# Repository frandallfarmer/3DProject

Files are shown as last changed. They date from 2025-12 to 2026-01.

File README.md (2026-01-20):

# D&D Terrain Pillar Connector

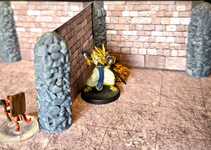
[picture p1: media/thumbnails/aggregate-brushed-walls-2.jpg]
Dry brushed aggregate pillars with dungeon walls
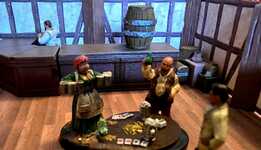
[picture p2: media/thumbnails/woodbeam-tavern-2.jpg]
Woodbeam pillars and tavern walls
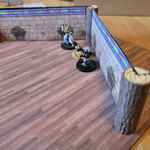
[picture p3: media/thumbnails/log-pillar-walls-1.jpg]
Two color log beams with temple walls
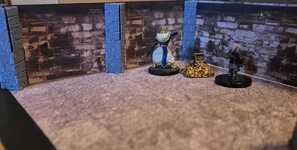
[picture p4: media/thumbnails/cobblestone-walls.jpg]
Cobblestone pillars with custom dungeon walls


3D printable pillar connector for tabletop RPG paper terrain [repo](https://github.com/frandallfarmer/3DProject) compatible with Paper Realm's tab-and-slot wall model. https://paperrealms.com

## Description

This pillar connector is designed to work with paper cardstock dungeon walls. The connector features slots on all four sides that accept paper wall tabs, allowing you to build modular dungeon interiors and building layouts. Paper Realms is also contributing templates and cutfiles for their tab-and-slot design model for anyone to customize for personal use!

This project was facilitated by [OldSchoolDM](http://oldschooldm.com), a paper-craft terrain aficionado, and implemented by [frankfarmer](https://github.com/frankfarmer). The driving desire was to support the minimum storage requirements for gaming terrain for dungeons and buildings. Inspired by the tab-and-slot design of Paper Realms, we wanted to add some heft - sturdiness and weight to the connectors. 3D Printing seemed like the perfect thing to hybrid with these compact but very detailed wall designs.

**[→ View 3D Models in Interactive Viewer](viewer.html)**

## The Walls

Paper Realms has contributed templates for you to customize your own paper walls to use with the 3D printed connectors (pillars) for this project.
These pillars are compatible with existing 2" Paper Realm's walls - that's been on of our requirements for this project.

See the walls [README](https://github.com/frandallfarmer/3DProject/tree/master/wall-templates) for more.

## The Pillars

### Specifications

- **Height:** 2 inches (50.8mm)
- **Cross-section:** 2/3" × 2/3" square (16.93mm)
- **Slots:** Four slots (one per face), centered, running 1" down from top
- **Construction:** Hollow with 2mm walls to save filament
- **File format:** STL for 3D printing

### Files

- `pillar_connector.scad` - OpenSCAD source file (parametric, editable)
- `pillar_connector.stl` - Ready-to-print STL file

### Printing

Standard PLA settings should work fine. The model is designed for FDM/FFF printers with typical 0.4mm nozzles.

 * Required:
  * "Detect thin walls" or "Wall generator: arachne"
 * Optional:
  * Nominal layer height: <= 0.20 mm
  * "Variable Layer Height"

Use "Detect thin walls" ensures your slicer doesn't skip the "paper-thin" segments that fit the wall slots.  Keeping these thin slots allows compatibilty with preexisting paper wall designs.

### Customization

The OpenSCAD file is parametric. Edit the parameters at the top of `pillar_connector.scad` to adjust:
- Pillar height
- Face width
- Slot dimensions
- Wall thickness

Regenerate the STL with:
```bash
openscad -o pillar_connector.stl pillar_connector.scad
```

## STL Viewer

This repository includes a web-based STL viewer for previewing all models. The viewer features:
- Split-screen interface with file list and 3D preview
- Interactive rotation and zoom controls
- Automatic file list generation

### Viewing Currently Available Models

**Online:** Visit https://frandallfarmer.github.io/3DProject/viewer.html to view all models in your browser.

**Locally:**

```bash
python3 -m http.server 8000
```
Then open http://localhost:8000/viewer.html in your browser.

## License

Everything here is under CC BY-SA-4.0, except the ViewSTL js files, which are under MIT - https://sourceforge.net/projects/viewstl/ for the latest.

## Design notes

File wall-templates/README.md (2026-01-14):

This project was inspired by the paper terrain from Paper Realms.

See https://paperrealms.com for links to their various paper terrain models, including several different wall designs (some shown in the photos you can see in the /media directory.

## Instructions

These .png files are templates you can use to create your own custom textured walls: 

1) Open the wall size you want in an image editor and paste your wall texture between the silver posts

2)  Print on heavy cardstock (at least 65lb/175gsm),

3) Cut using 

   a hobby knife or

   the matching file provided in ./cutfiles with a Silhouette cutting machine

4) Fold in half and use a black marker to edge the top/bottom.

5) Glue.

6) Let dry under some weight.

7) Enjoy!

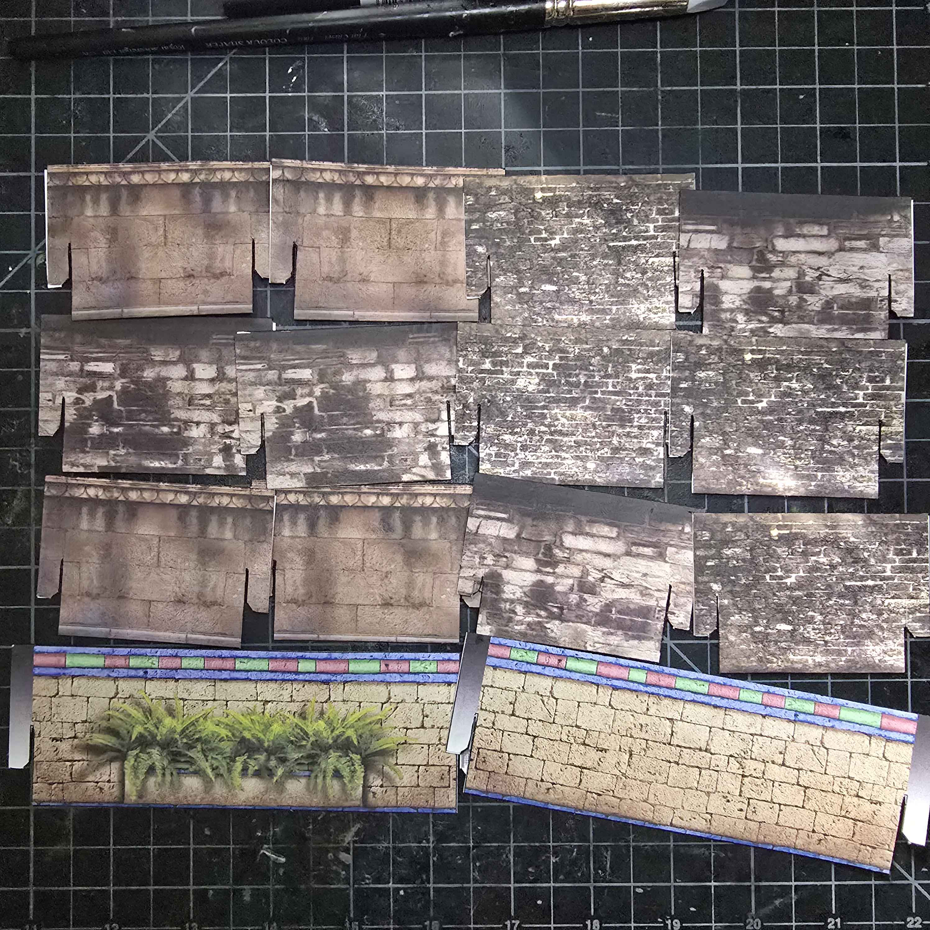
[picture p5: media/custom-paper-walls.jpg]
kitbashed walls


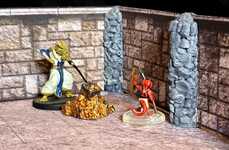
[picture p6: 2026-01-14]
media/thumbnails/aggregate-brushed-walls-3.jpg

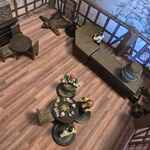
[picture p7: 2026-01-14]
media/thumbnails/woodbeam-tavern-1.jpg

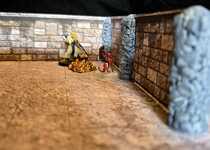
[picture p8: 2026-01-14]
media/thumbnails/aggregate-brushed-walls-1.jpg

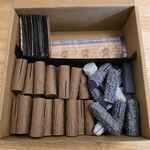
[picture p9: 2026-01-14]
media/thumbnails/box-of-walls-and-posts.jpg

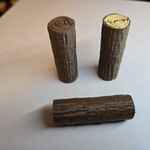
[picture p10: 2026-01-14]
media/thumbnails/1-and-2-color-logs.jpg

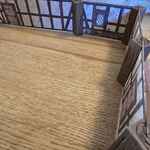
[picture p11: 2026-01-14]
media/thumbnails/woodbeam-tavern-3.jpg

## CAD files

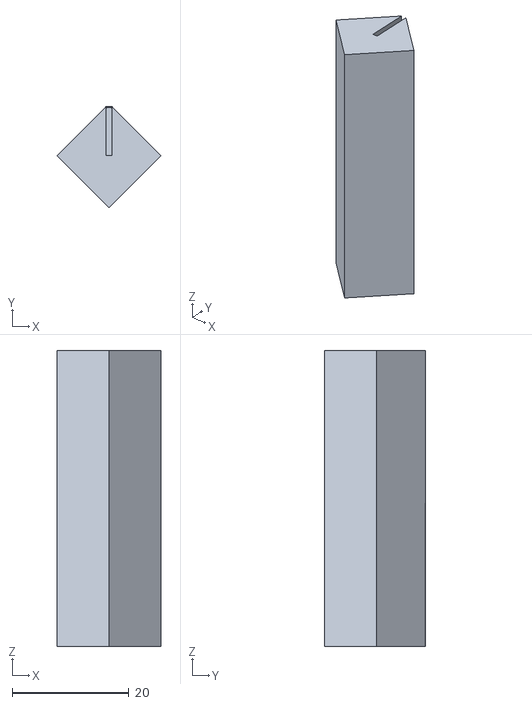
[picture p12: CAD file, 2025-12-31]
built_stls/output_slimrect_end.stl
17.9 x 17.4 x 50.8

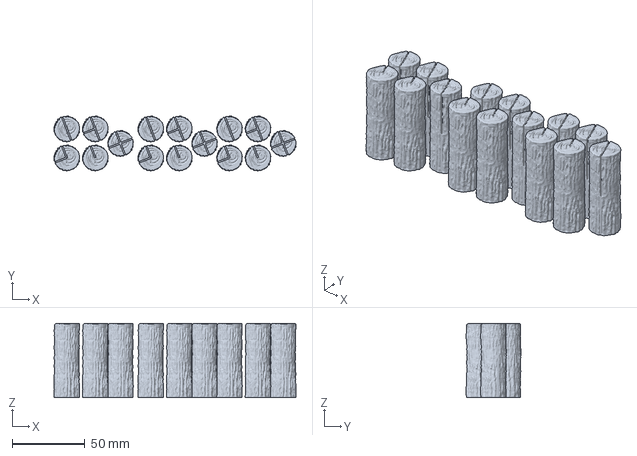
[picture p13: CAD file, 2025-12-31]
log_with_color.3mf
166.0 x 37.8 x 50.8 mm

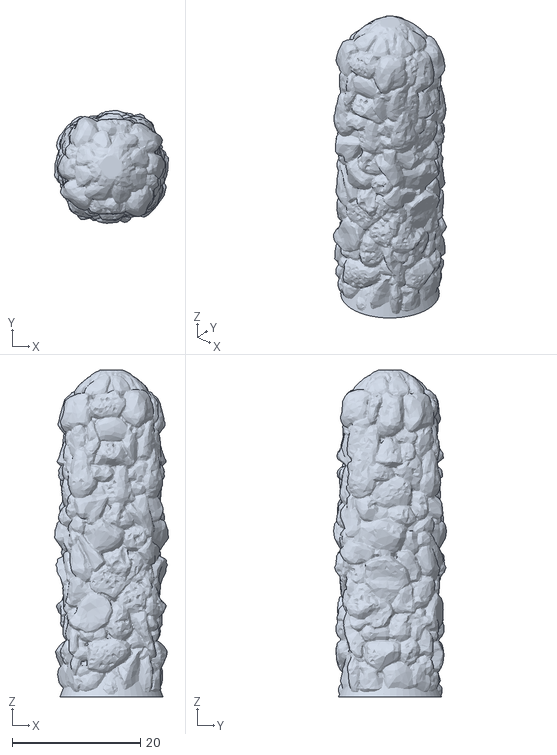
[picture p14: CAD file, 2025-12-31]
src/aggregate.stl
17.8 x 17.6 x 51.0

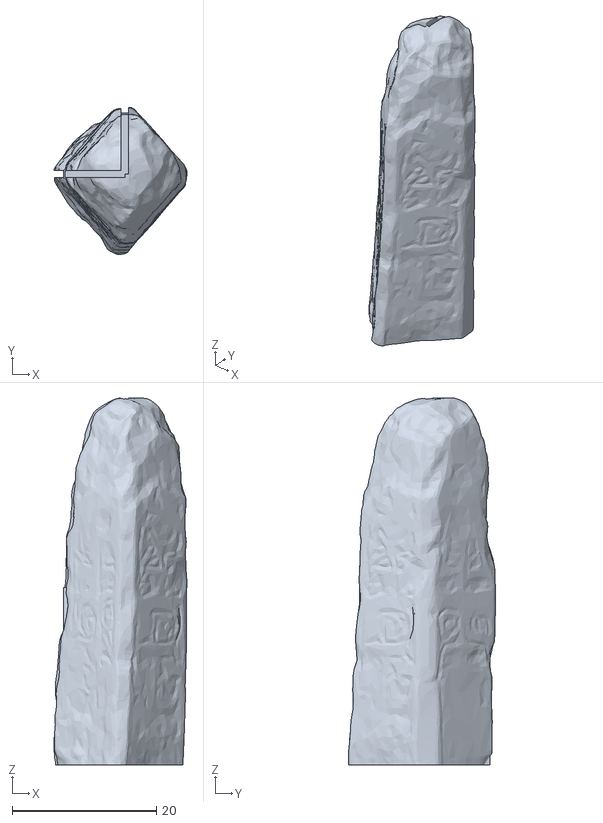
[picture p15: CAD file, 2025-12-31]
built_stls/output_slimhengestone_corner.stl
18.4 x 20.4 x 50.8

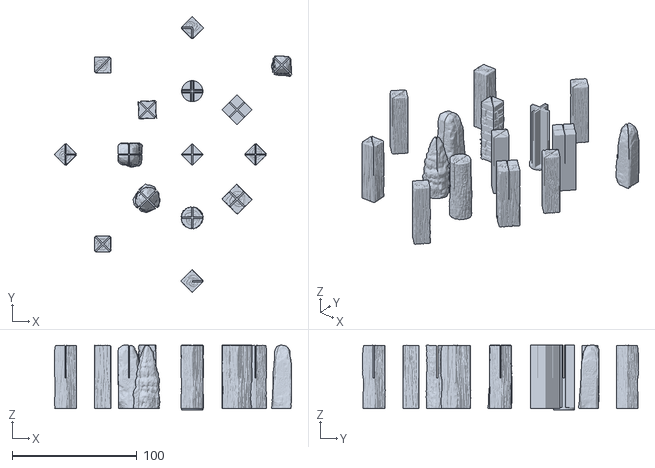
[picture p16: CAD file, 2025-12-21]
connectors.stl
190.5 x 221.4 x 51.8

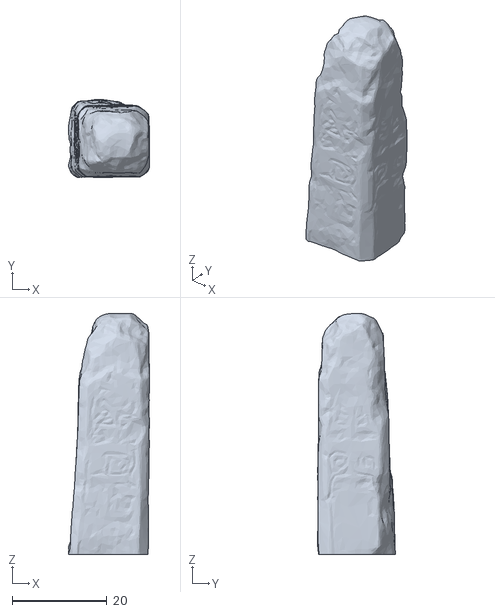
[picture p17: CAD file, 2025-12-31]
src/hengestone.stl
17.2 x 16.5 x 51.0

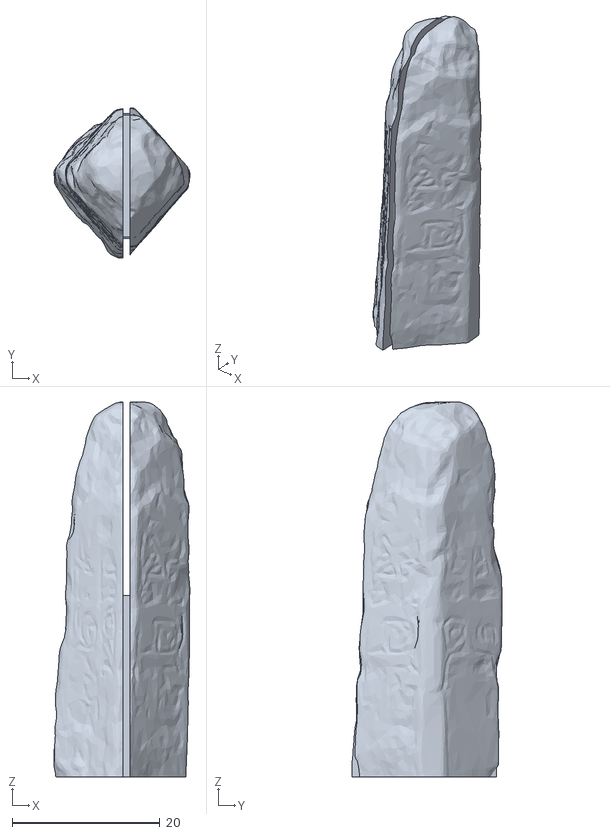
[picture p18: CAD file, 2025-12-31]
built_stls/output_slimhengestone_straight.stl
18.4 x 20.4 x 50.8

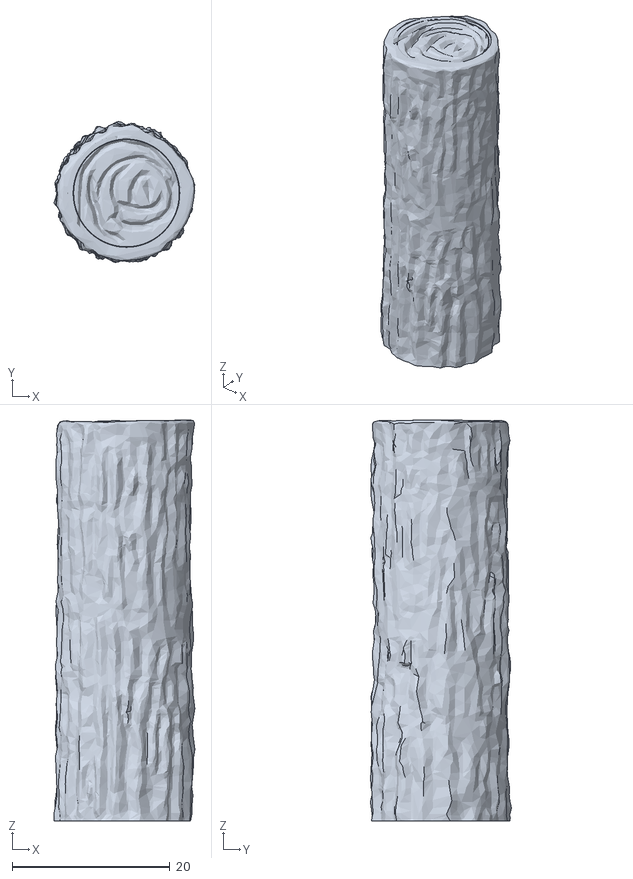
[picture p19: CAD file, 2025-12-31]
src/log.stl
17.8 x 17.9 x 50.8

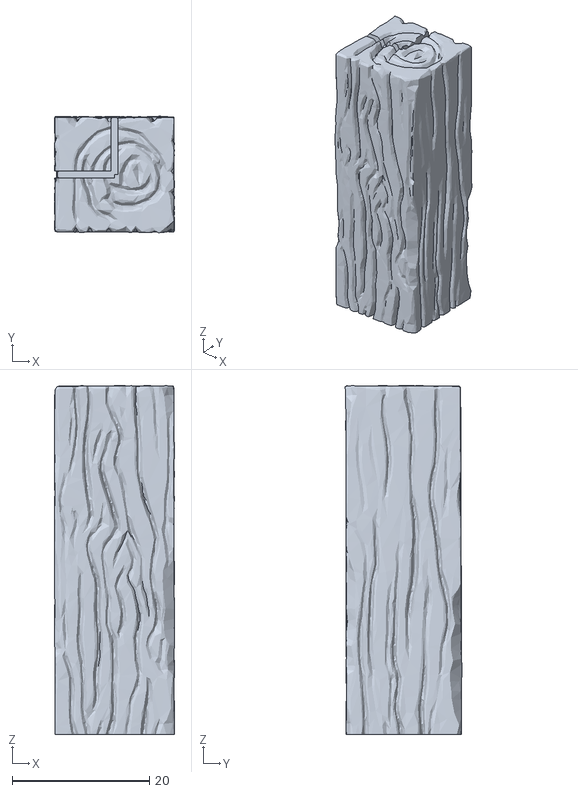
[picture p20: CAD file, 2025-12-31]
built_stls/output_woodbeam_corner.stl
17.5 x 17.0 x 50.8

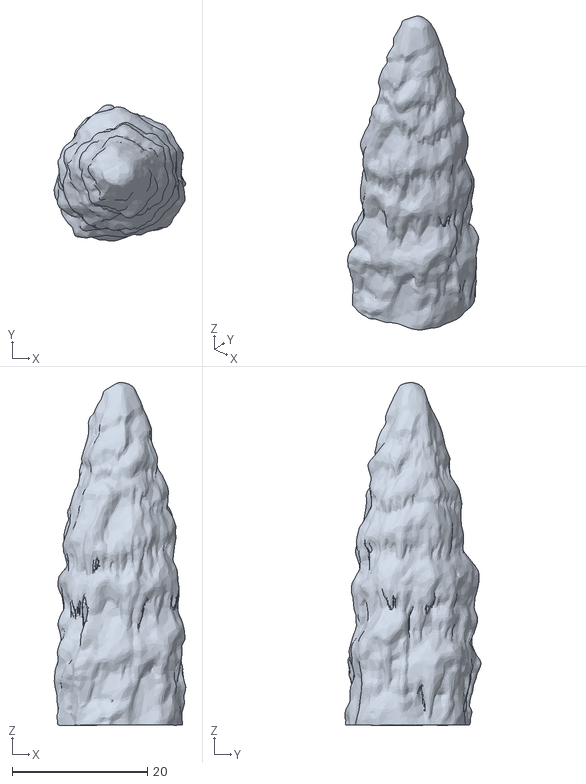
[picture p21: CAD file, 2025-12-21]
src/stalagmite.stl
19.5 x 20.2 x 50.8

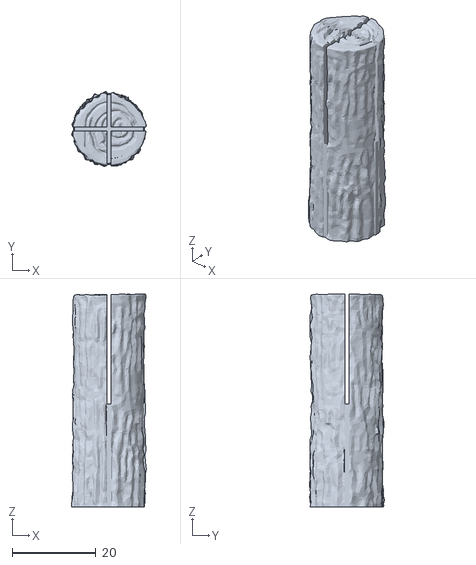
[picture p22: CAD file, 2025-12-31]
built_stls/output_log_allways.stl
17.8 x 17.9 x 50.8

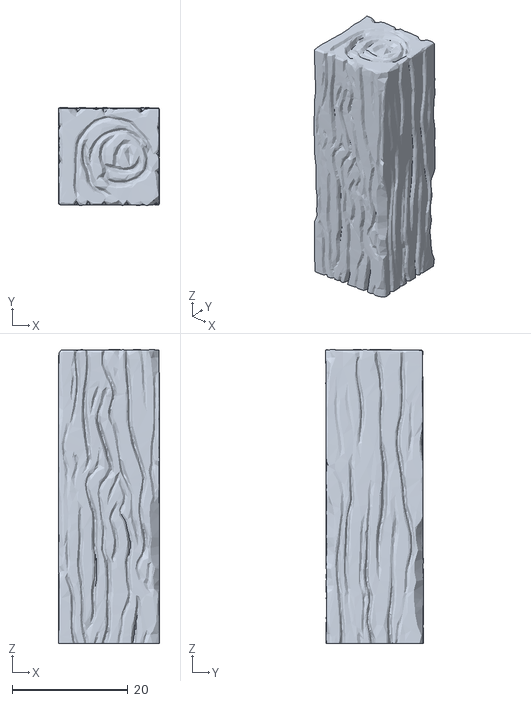
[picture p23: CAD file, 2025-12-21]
src/wood_beam.stl
17.5 x 17.0 x 50.8

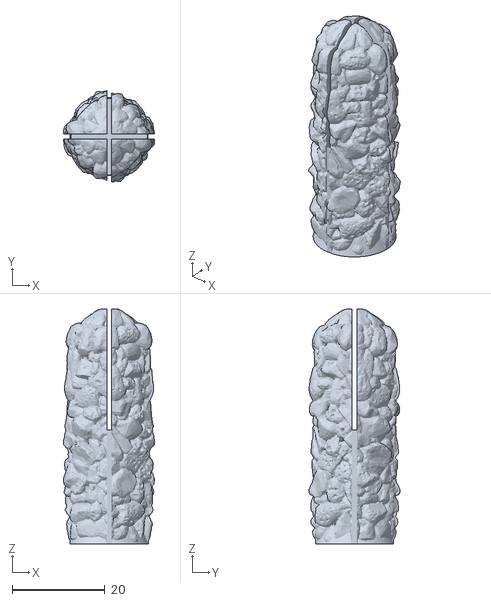
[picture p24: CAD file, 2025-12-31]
built_stls/output_aggregate_allways.stl
19.8 x 19.8 x 50.8

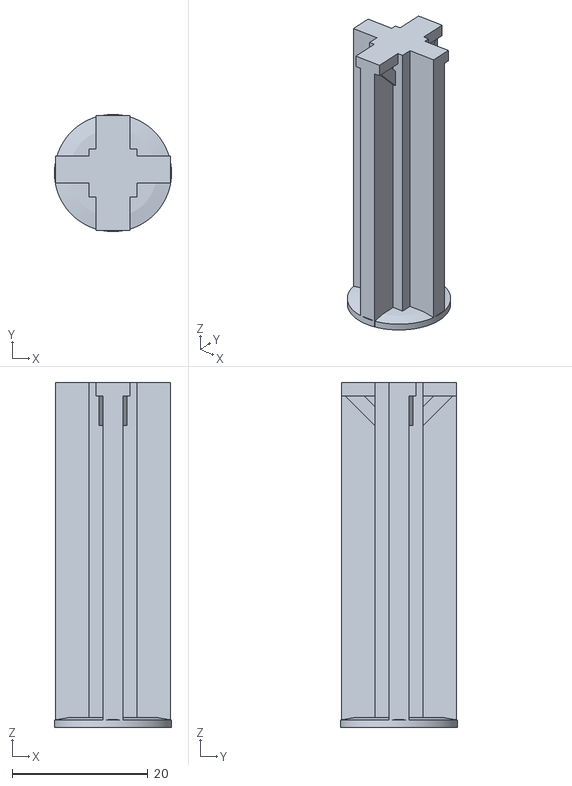
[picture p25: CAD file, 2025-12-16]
src/mine_framework.stl
17.3 x 17.2 x 50.8

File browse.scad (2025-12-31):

include <connectors.scad>;

// DEBUG SCRIPT DISPLAYS ALL MODELS
// Rendering all models from here seems to be slow and single threaded
// so I don't recommend using this file to actually render an STL -- but
// it's handy for debugging geometry during development

module display_all_stls() {

    display_pos(00) { build_byname("slimrect"); };
    display_pos(01) { build_byname("origrect"); };
    display_pos(02) { build_byname("cruciform"); };
    display_pos(03) { build_byname("cobblewall"); };
    display_pos(04) { build_byname("hengestone"); };
    display_pos(05) { build_byname("stalagmite"); };
    display_pos(06) { build_byname("log"); };
    display_pos(07) { build_byname("woodbeam"); };
    display_pos(08) { build_byname("slimbeam"); };
    display_pos(09) { build_byname("slimhengestone"); };
    display_pos(10) { build_byname("aggregate"); };

/*
// source stl defective
    display_pos(20) {
        wallify(all=1) { import("src/mine_framework.stl"); }};
*/
}

module display_all_tab_variants() {
    display_pos(0) {
        wallify(b=1) { children(0); }};
    display_pos(1) {
        wallify(c=1) { children(0); }};
    display_pos(2) {
        wallify(b=1,c=1) { children(0); }};
    display_pos(3) {
        wallify(b=1,c=1,d=1) { children(0); }};
    display_pos(4) {
        wallify() { children(0); }};
}

display_all_stls();
//display_all_tab_variants() { PILLAR_smallbeam(); };
//wallify(c=1) { PILLAR_slim_diag_rect(); };

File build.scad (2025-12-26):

include <connectors.scad>;


model = "slimbeam";
variant = "tee";

build_byname(model, variant);

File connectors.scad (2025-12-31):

//             //
// DEFINES     //
//             //

pillar_height_inch = 2;
face_width_inch = 0.666666;
slot_height_inch = 1;
tab_width_inch = 0.25;
wall_width    = 1.0;             // Width of slot (for cardstock thickness + clearance)
kerf          = 1.0;             // cut between tab and wall
tolerance     = 0.8;             // allow wiggle room below tab


// the calculated values below don't show up in the openscad customizer pane
function inch_to_mm(inches) = inches * 25.4;

pillar_height = inch_to_mm(pillar_height_inch);    // 2 inches in mm
face_width    = inch_to_mm(face_width_inch);  // 2/3 inch in mm
slot_height   = inch_to_mm(slot_height_inch);   // Height of slot (1 inch, from top down)
tab_height    = slot_height + inch_to_mm(0.5); // tab extends 1/2" below the slot
tab_width     = inch_to_mm(tab_width_inch);


module get_modelname(i) {
    if (i == "slimrect") PILLAR_slim_diag_rect();
    else if (i == "origrect") PILLAR_original_rect();
    else if (i == "cruciform") PILLAR_cruciform();
    else if (i == "cobblewall") import("src/pillar_cobblewall.stl");
    else if (i == "hengestone") PILLAR_hengestone();
    else if (i == "stalagmite") PILLAR_cave();
    else if (i == "log") import("src/log.stl");
    else if (i == "woodbeam") import("src/wood_beam.stl");
    else if (i == "slimbeam") PILLAR_smallbeam();
    else if (i == "slimhengestone") PILLAR_smallhengestone();
    else if (i == "aggregate") PILLAR_aggregate();
}
module wallify_variantname(variant) {
    if (variant == "end")           wallify()        children(0);
    else if (variant == "corner")   wallify(b=1)     children(0);
    else if (variant == "straight") wallify(c=1)     children(0);
    else if (variant == "tee")      wallify(b=1,c=1) children(0);
    else if (variant == "allways")  wallify(all=1)   children(0);
}

module build_byname(model, variant="allways") {
    wallify_variantname(variant) get_modelname(model) ;
}

//                        //
// Pillar model variants  //
//                        //

module PILLAR_original_rect() {
    // the original paper rectangle
    translate([0,0,pillar_height/2])
        cube([face_width, face_width, pillar_height], true);
}

module PILLAR_slim_diag_rect() {
    // rotate 45 degrees for a slimmer rectangle

    // rotated square is sqrt(2) wide, plus a little extra to fit the tab
    face = face_width / sqrt(2) + (kerf/1.5);

    rotate([0,0,45]) //45 degrees around z axis
        translate([0,0,pillar_height/2])
        cube([face, face, pillar_height], true);
}

module PILLAR_cruciform() {
    rotate([0,0,0])
        translate([0,0,pillar_height/2])
        cube([wall_width * 3, face_width, pillar_height], true);
    rotate([0,0,90])
        translate([0,0,pillar_height/2])
        cube([wall_width * 3, face_width, pillar_height], true);
    cylinder(h=2, d=face_width, center=true);
}

module PILLAR_caveold() {
    // this first POC model is too ugly and treelike
    width = 24;
    difference() {
        resize([width+1, width, 56])
            import("src/pillar_cave.stl");
        trim_top(1);
        bounding_cyl(24);
    }
}

module PILLAR_cave() {
    width = 21;

    resize([width+1, width, pillar_height])
        import("src/stalagmite.stl");
}

module PILLAR_hengestone() {
    hengewidth = 19.5;
    translate([-1,0.5,0])
        resize([hengewidth, hengewidth, pillar_height])
        import("src/hengestone.stl");
}


module PILLAR_aggregate() {
    mywidth = 19.8;
    resize([mywidth, mywidth, pillar_height])
        rotate([0,0,45])
        import("src/aggregate.stl");
}

module PILLAR_smallbeam () {
    beamwidth = 19 / sqrt(2);
    rotate([0,0,45])
        resize([beamwidth, beamwidth, pillar_height])
        import("src/wood_beam.stl");
}

module PILLAR_smallhengestone () {
    hengewidth = 26 / sqrt(2);

    resize([hengewidth, hengewidth+2, pillar_height])
        rotate([0,0,45])
        PILLAR_hengestone();
}



//             //
// LIBRARY     //
//             //


module wall_cut(rotation) {
    rotate([0,0,rotation])
        translate([-wall_width/2, 0, pillar_height - tab_height - tolerance])
        cube([wall_width, pillar_height, tab_height+tolerance]);

    rotate([0,0,rotation])
        translate([-wall_width/2, face_width/2, 0])
        cube([wall_width, pillar_height, pillar_height]);
}

module cut_walls(rotation) {
    // first we cut space
    difference() {
        children(0);
        wall_cut(rotation);
    }
    // then backfill the tab that fits in the kerf
    fill_tab(rotation);
}

module fill_tab(rotation) {
    rotate([0,0,rotation])
        translate([-wall_width / 2, (face_width / 2) - kerf + tolerance, 0])
        maketab();
}

module maketab() {
    curtain_rotation = 75;
    union() {
        translate([-0.08, 0, 0])
            cube([wall_width + .16, kerf - tolerance, pillar_height - slot_height - tolerance]);

        translate([wall_width - .11, .15, 0])
            rotate([0,0,-curtain_rotation])
            cube([wall_width, kerf - tolerance, pillar_height - slot_height - tolerance]);
        translate([-0.15, .18 -wall_width, 0])
            rotate([0,0,curtain_rotation])
            cube([wall_width, kerf - tolerance, pillar_height - slot_height - tolerance]);
    }
}

// create slots in a pillar
module wallify(b=0, c=0, d=0, all=0) {

    cut_walls(0)
        cut_walls(090 * (b+all))
        cut_walls(180 * (c+all))
        cut_walls(270 * (d+all))
        children(0);
}

//move a completed shape into display position
module display_pos(pos) {
    row = ceil((pos) / 8);
    rotate([0, 0, 45 * pos])
        translate([row * pillar_height, 0, 0])
        children(0);
}

module trim_top(offset=0) {
    translate([0,0,pillar_height*2-offset])
        cube([100,100,100], center=true);
}

module bounding_cyl(diameter) {
    difference() {
        cylinder(pillar_height,100,center=true);
        cylinder(pillar_height, d=diameter, center=true);
    }
}

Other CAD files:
built_stls/output_cobblewall_straight.stl
src/pillar_cobblewall.stl
built_stls/output_stalagmite_corner.stl
src/pillar_cave.stl
built_stls/output_aggregate_corner.stl
built_stls/output_aggregate_end.stl
built_stls/output_aggregate_straight.stl
built_stls/output_aggregate_tee.stl
built_stls/output_cobblewall_allways.stl
built_stls/output_cobblewall_corner.stl
built_stls/output_cobblewall_end.stl
built_stls/output_cobblewall_tee.stl
built_stls/output_cruciform_allways.stl
built_stls/output_cruciform_corner.stl
built_stls/output_cruciform_end.stl
built_stls/output_cruciform_straight.stl
built_stls/output_cruciform_tee.stl
built_stls/output_hengestone_allways.stl
built_stls/output_hengestone_corner.stl
built_stls/output_hengestone_end.stl
built_stls/output_hengestone_straight.stl
built_stls/output_hengestone_tee.stl
built_stls/output_log_corner.stl
built_stls/output_log_end.stl
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

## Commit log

2025-12-06 Initial commit: D&D terrain pillar connector
    Add 3D printable pillar connector for paper cardstock terrain:
    - OpenSCAD parametric source file
    - STL file ready for printing
    - 2" tall, 2/3" square cross-section
    - Four slots for wall tabs
    [pillar_connector.scad, pillar_connector.stl]
2025-12-07 the back wall slot didn't penetrate correctly. This looks better in previz
    [pillar_connector.scad, pillar_connector.stl]
2025-12-16 Rebuild SCAD to turn arbitrary geometry into suitable wall connectors
    [connectors.scad, connectors.stl, pillar_beam.stl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]
2025-12-16 Cut an additional 0.4mm tolerance for better wall fit
    [connectors.scad, connectors.stl]
2025-12-16 restore render all
    [connectors.scad]
2025-12-26 parallelized build process using powershell
    [browse.scad, build.scad, connectors.scad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]
2025-12-31 Add aggregate pillar type resembling loose stones. Generally enhanced print quality
    [aggregate.stl, browse.scad, connectors.scad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]
2026-01-13 Adding first page for Github Pages support - a StL viewer.
2026-01-13 Fix STL viewer container height
2026-01-13 Fix STL file paths - use relative path from js directory
2026-01-13 Add Pandoc conversion: README.md → index.html, move viewer to viewer.html
2026-01-15 Add path filters and caching to deploy-pages workflow
    - Only runs when relevant files change (README.md, style.css, viewer.html, etc.)
    - Caches generated index.html keyed by README.md hash
    - Only regenerates index.html if README.md actually changed
    - Prevents unnecessary Pandoc runs and index.html overwrites
